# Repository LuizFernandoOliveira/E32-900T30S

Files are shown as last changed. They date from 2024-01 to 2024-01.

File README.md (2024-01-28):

# E32-900T30S Shield
 LoRa IoT Module

Electronic circuit designed to communicate between the E32-900T30S module and a microcontrolled/embedded system.

- The J1 connector is designed to fit into a Raspberry Pi.
- The J2 connector was designed to be used on a breadboard.
- The J3 connector was designed to be used with other projects (by the author) that have this type of connector.
- The control signal "LORA_ON" allows turning the module on and off.
- The GND_ON control signal is a signal sent from another board that enables/disables the board's GND. In this case, resistor R1 must be soldered. If you don't need to control the board's GND, just solder resistor R2.

**Front-view:**

Front-view

**Back-view:**

Back-view

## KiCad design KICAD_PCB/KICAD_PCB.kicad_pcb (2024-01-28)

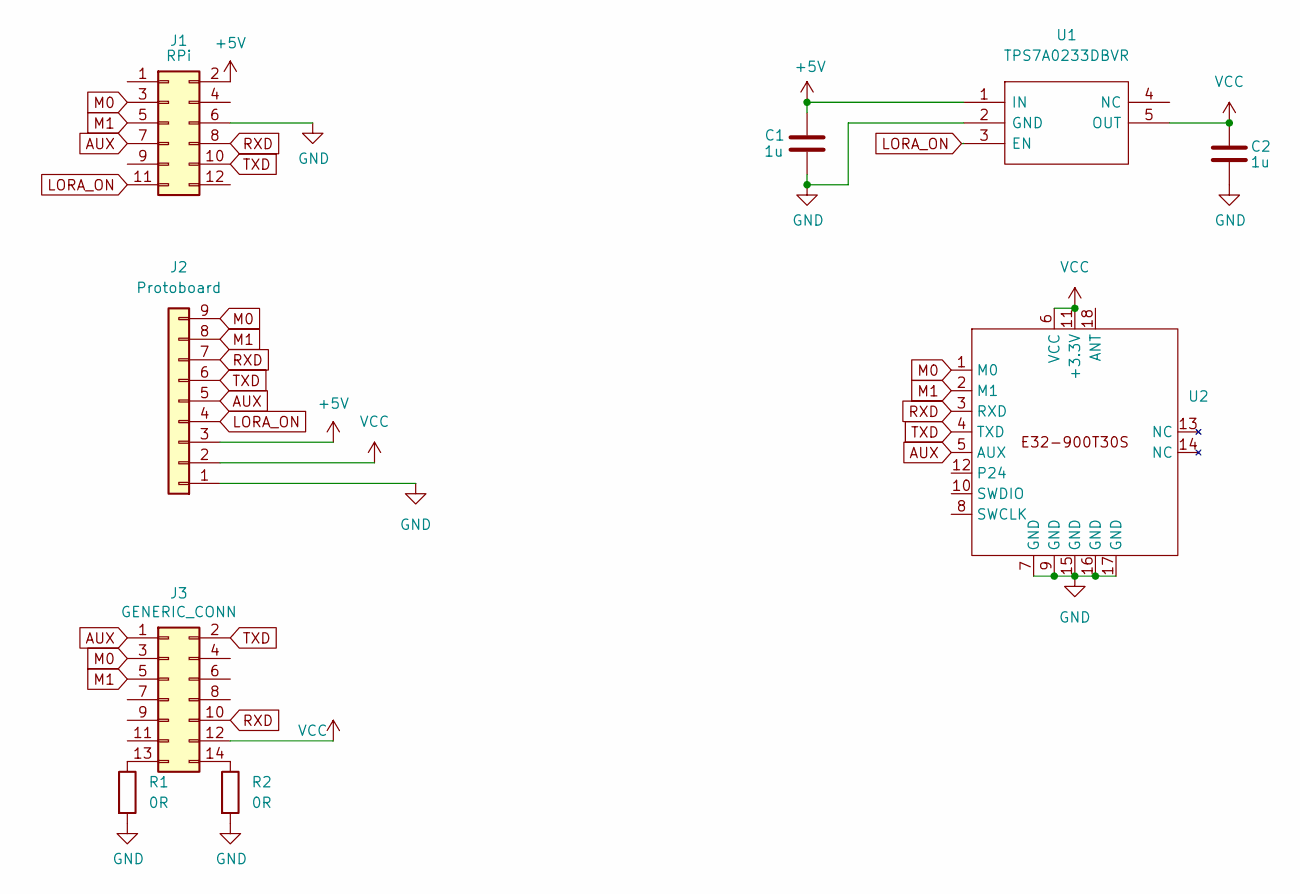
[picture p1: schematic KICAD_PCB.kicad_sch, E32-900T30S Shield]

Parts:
C1, C2: 1u; C_0805_2012Metric
J1: RPi; PinSocket_2x06_P2.54mm_Vertical
J2: Protoboard; PinHeader_1x09_P2.54mm_Horizontal
J3: GENERIC_CONN; PinSocket_2x07_P2.54mm_Vertical
R1, R2: 0R; R_0805_2012Metric
U1: TPS7A0233DBVR; SOT-23-5; Manufacturer_Part_Number TPS7A0233DBVR; Mouser Part Number 595-TPS7A0233DBVR
U2: E32-900T30S

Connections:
+5V: C1.1, J1.2, J2.3, U1.1 (IN)
AUX: J1.7, J2.5, J3.1, U2.5 (AUX)
GND: C1.2, C2.2, J1.6, J2.1, R1.2, R2.2, U1.2 (GND), U2.7 (GND), U2.9 (GND), U2.15 (GND), U2.16 (GND), U2.17 (GND)
LORA_ON: J1.11, J2.4, U1.3 (EN)
M0: J1.3, J2.9, J3.3, U2.1 (M0)
M1: J1.5, J2.8, J3.5, U2.2 (M1)
unnamed: J3.13, R1.1
unnamed: J3.14, R2.1
RXD: J1.8, J2.7, J3.10, U2.3 (RXD)
TXD: J1.10, J2.6, J3.2, U2.4 (TXD)
VCC: C2.1, J2.2, J3.12, U1.5 (OUT), U2.6 (VCC), U2.11 (+3.3V)

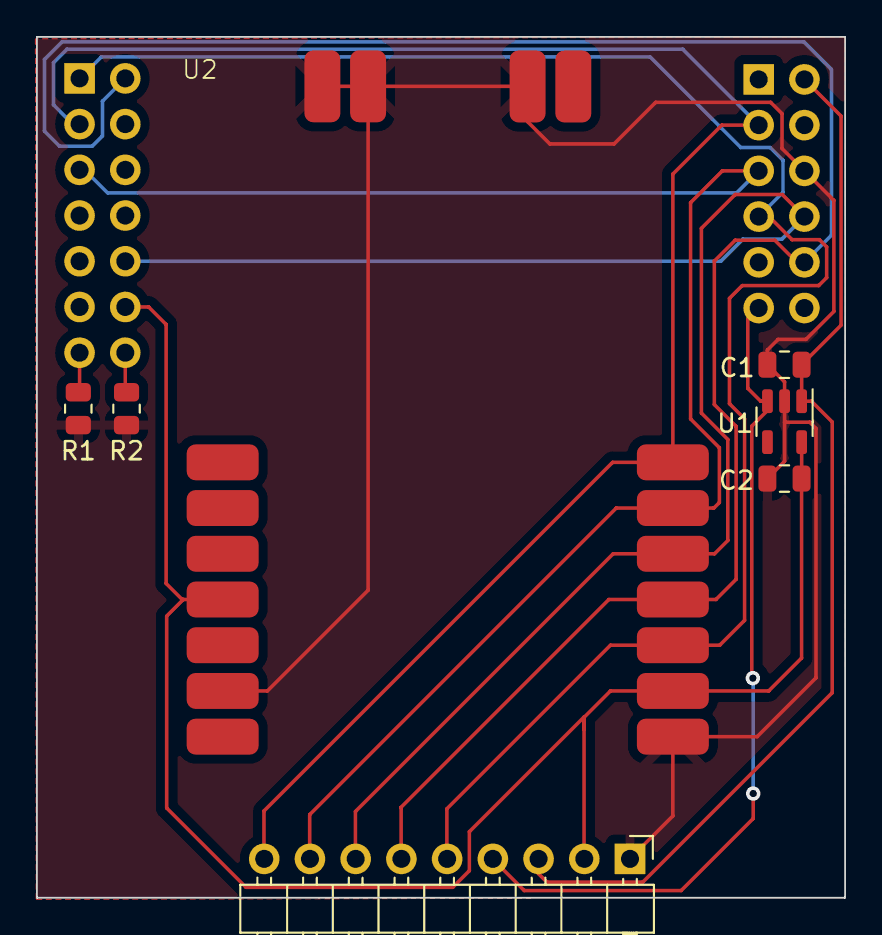
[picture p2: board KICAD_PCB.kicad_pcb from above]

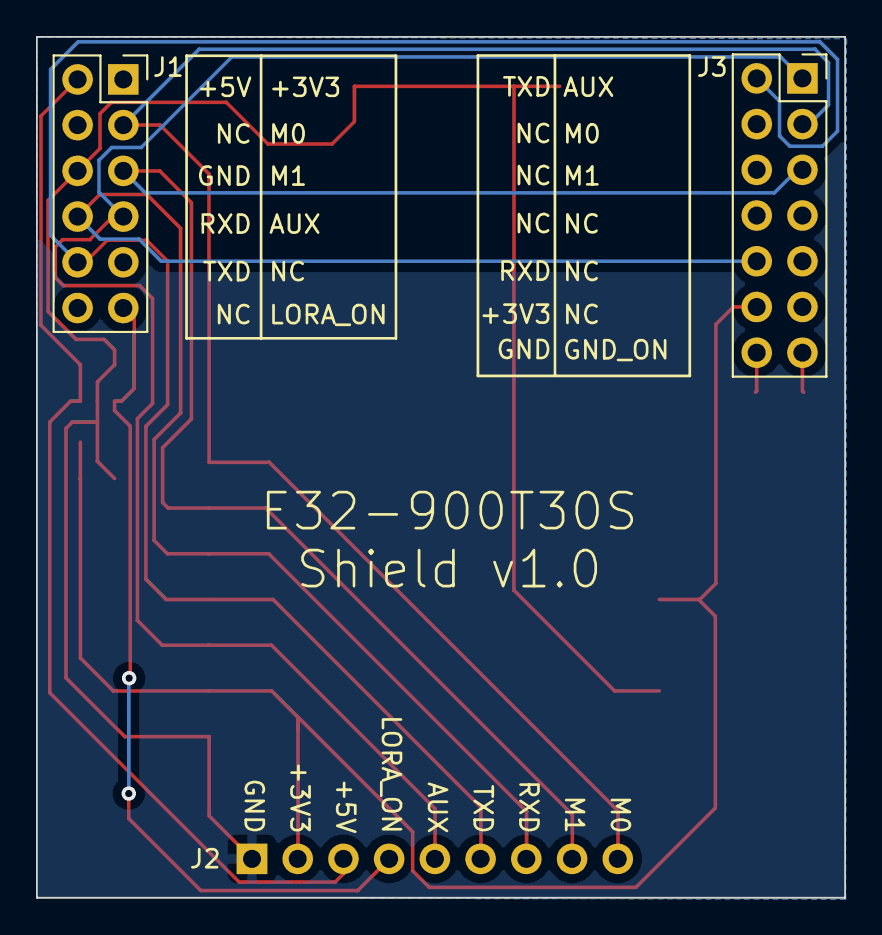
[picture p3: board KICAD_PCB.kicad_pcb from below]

Board: 2 copper layers, 44.9 x 47.8 mm, 9 parts (2 on the bottom side), 11 nets.

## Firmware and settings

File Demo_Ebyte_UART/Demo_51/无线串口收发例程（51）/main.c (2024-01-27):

/**
  ******************************************************************************
  * @author  WuShihong
  * @version V1.0
  * @date    2016-03-27
  * @brief   
  ******************************************************************************
  * @attention
  *
  * 成都亿佰特电子科技有限公司    :http://www.cdebyte.com
  * 官方淘宝直营 :http://yhmcu.taobao.com
  * 阿里巴巴:http://http://shop1399568656388.1688.com
  ******************************************************************************
  */ 
#include <at89x52.h>
#define uchar unsigned char
#define uint unsigned int

sbit K1 = P3^2;//设置P3.2口为按键端口
sbit LED = P2^7;//设置P2.7口为按键端口

uchar Error;	  //验证标志

uchar code table[] = "Ebyte";
uchar table1[] = "01234";


void delay (uint time)
{
	uint i;
	uint j;
	for (i=0; i<time; i++)
		for (j=0; j<110; j++);
}

void inital (void)
{
	LED = 1;//默认熄灭
	SM0 = 0;
	SM1 = 1;//工作方式1
	//SMOD = 0;//波特率不加倍(默认)
	REN = 1;//允许接受
	TMOD = 0X20;//T1工作于方式2：自动重装初值
	TH1 = 0XFD;
	TL1 = 0XFD;	//此初值波特率为：9600bps
	TR1 = 1;	//定时器是用来作为波特率的发生器
//	EA = 1;
//	ES = 1;	
}

void Check_Data (void)
{
	uchar i;
	
	for (i=0;i<6;i++)
	{
		if(table1[i]==table[i])
			Error = 0;
		else
		{
			Error = 1;
			break;	
		}
	}	
}

void Send_and_Sin_Data (void)
{
	uchar i;
	for (i=0;i<6;i++)
	{
		SBUF = table[i];
		while (TI == 0);//等待发送结束
		TI = 0;
		while (RI == 0);//发送和接受同步进行，发送结束后，等待接受结束
		RI = 0;
		table1[i] = SBUF;//接受端
	}
}

void main ()
{
	uchar i;

	inital ();
	while (1)
	{
		for (i=0;i<6;i++)
			table1[i] = i;//数组清空
	
		if(K1 == 0)
		{
			delay (10);
			if(K1 == 0)
			{
				Send_and_Sin_Data ();//发送并接受数据
				Check_Data ();//验证接受的数据
				if (Error == 0)//判断接受的正确性
				{
					LED = 0;		//亮
					delay (50);
					LED = 1;		//灭
				}
			}
		}
	}
}
